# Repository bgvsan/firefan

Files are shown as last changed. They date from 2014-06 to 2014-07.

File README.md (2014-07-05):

Fire Fan
=======

A minimal board for your Fire, manage temperature and 220 Volt Fan.

File Available
=======

-- Eagle Pcb Files (schematics, board, gerber)
-- Microcontroller source code and Hex file
-- Bom list

License
=====
See [License] (LICENSE) file.

Support
======
For any problem or support request mail to me[@]diegosantinelli.it

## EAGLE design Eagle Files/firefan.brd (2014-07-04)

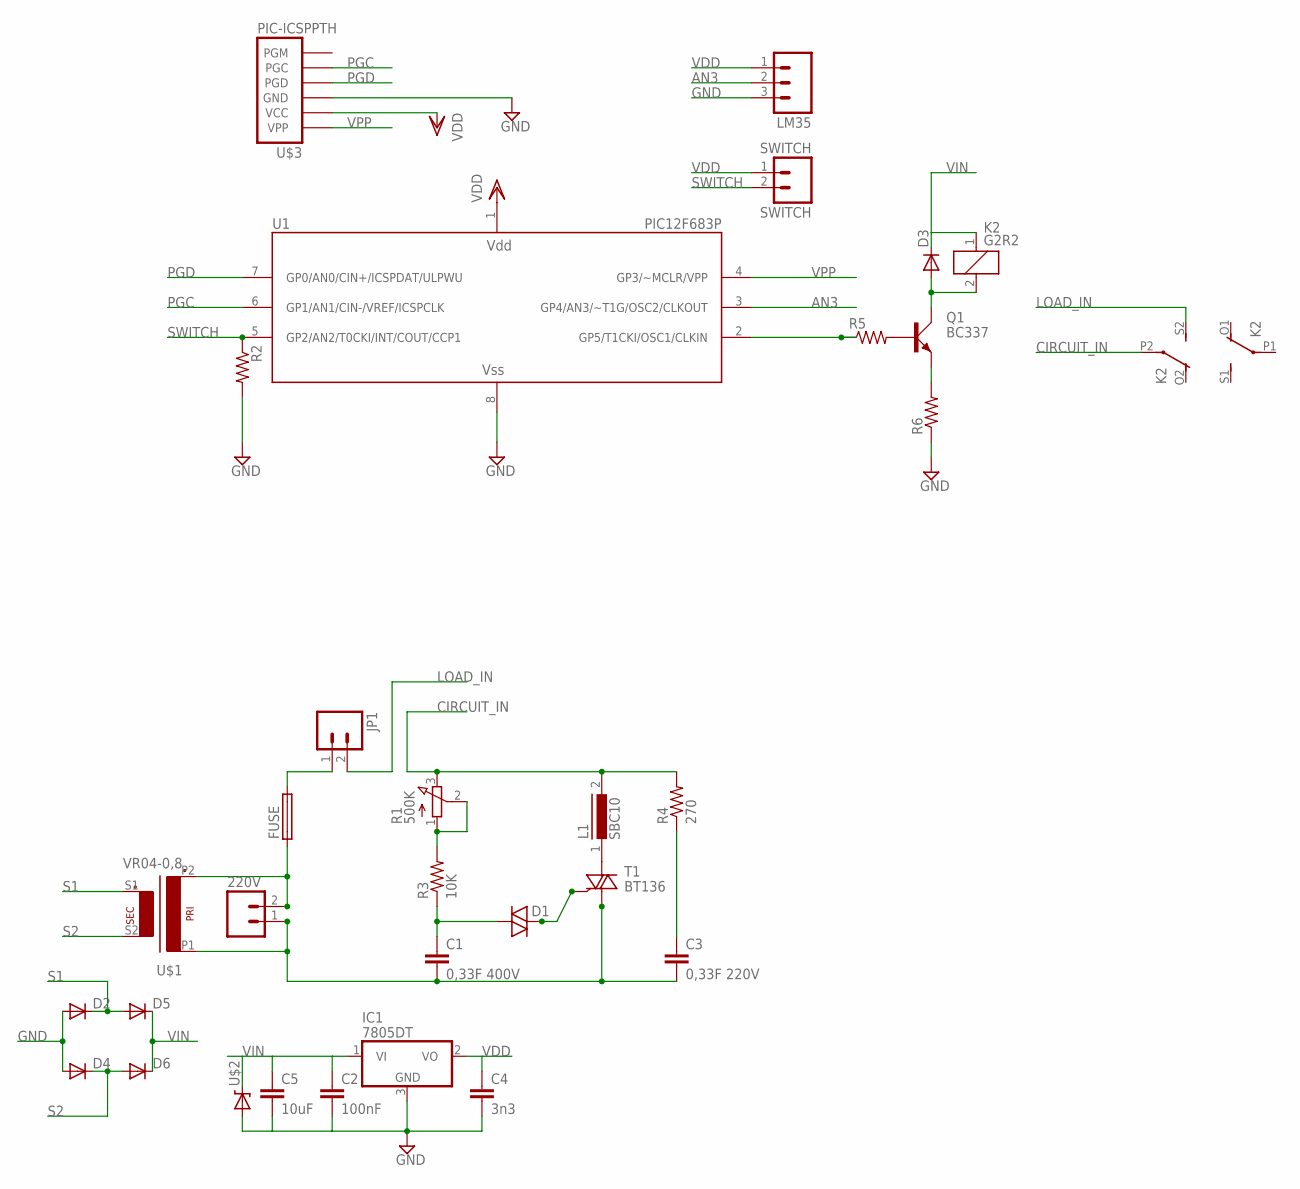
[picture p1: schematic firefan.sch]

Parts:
220V: M023.5MM-NO_SILK; SCREWTERMINAL-3.5MM-2-NS
C1: 0,33F 400V; CAP-PTH-5MM
C2: 100nF; CAP-PTH-5MM
C3: 0,33F 220V; CAP-PTH-5MM
C4: 3n3; CAP-PTH-5MM
C5: 10uF; CAP-PTH-5MM
D1: DIAC-DO35-10; DO35-10
D2, D3, D4, D5, D6: 1N4004; DO41-10
FUSE: SH22,5A
IC1: 7805DT; TO252
JP1: M023.5MM-NO_SILK; SCREWTERMINAL-3.5MM-2-NS
K2: G2R2
L1: SBC10
LM35: M03LONGPADS; 1X03_LONGPADS
Q1: BC337; SOT54A
R1: 500K; 3RP/1610N
R2, R5, R6: RESISTORPTH-1/4W; AXIAL-0.4
R3: 10K; AXIAL-0.5
R4: 270; AXIAL-0.5
SWITCH: SWITCH; SCREWTERMINAL-3.5MM-2-NS
T1: BT136; TO220AB
U1: PIC12F683P; DIP-8
U$1: VR04-0,8
U$2: DIODE-ZENERPTH; DIODE-ZENER
U$3: PIC-ICSPPTH; MOLEX-1X6

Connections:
AN3: LM35.2, U1.3 (GP4/AN3/~T1G/OSC2/CLKOUT)
CIRCUIT_IN: K2.P2, L1.2, R1.3 (E), R4.P$2 (2)
GND: C2.2, C4.2, C5.2, D2.A, D4.A, IC1.3 (GND), LM35.3, R2.P$2 (2), R6.P$1 (1), U1.8 (VSS), U$2.P$2 (A), U$3.3 (GND)
LOAD_IN: JP1.2, K2.S2 (S)
unnamed: FUSE.2, JP1.1
unnamed: D1.C (2), T1.3 (G)
unnamed: R1.1 (A), R1.2 (S), R3.P$2 (2)
unnamed: L1.1, T1.2 (A2)
unnamed: C1.1, D1.A (1), R3.P$1 (1)
unnamed: C3.1, R4.P$1 (1)
unnamed: 220V.1, C1.2, C3.2, T1.1 (A1), U$1.P1
unnamed: 220V.2, FUSE.1, U$1.P2
unnamed: Q1.B, R5.P$2 (2)
unnamed: Q1.E, R6.P$2 (2)
unnamed: D3.A, K2.2, Q1.C
PGC: U1.6 (GP1/AN1/CIN-/VREF/ICSPCLK), U$3.5 (PGC)
PGD: U1.7 (GP0/AN0/CIN+/ICSPDAT/ULPWU), U$3.4 (PGD)
RELAIS: R5.P$1 (1), U1.2 (GP5/T1CKI/OSC1/CLKIN)
S1: D2.C, D5.A, U$1.S1 (S3)
S2: D4.C, D6.A, U$1.S2 (S4)
SWITCH: R2.P$1 (1), SWITCH.2, U1.5 (GP2/AN2/T0CKI/INT/COUT/CCP1)
VDD: C4.1, IC1.2 (VO), LM35.1, SWITCH.1, U1.1 (VDD), U$3.2 (VCC)
VIN: C2.1, C5.1, D3.C, D5.C, D6.C, IC1.1 (VI), K2.1, U$2.P$1 (C)
VPP: U1.4 (GP3/~MCLR/VPP), U$3.1 (VPP)

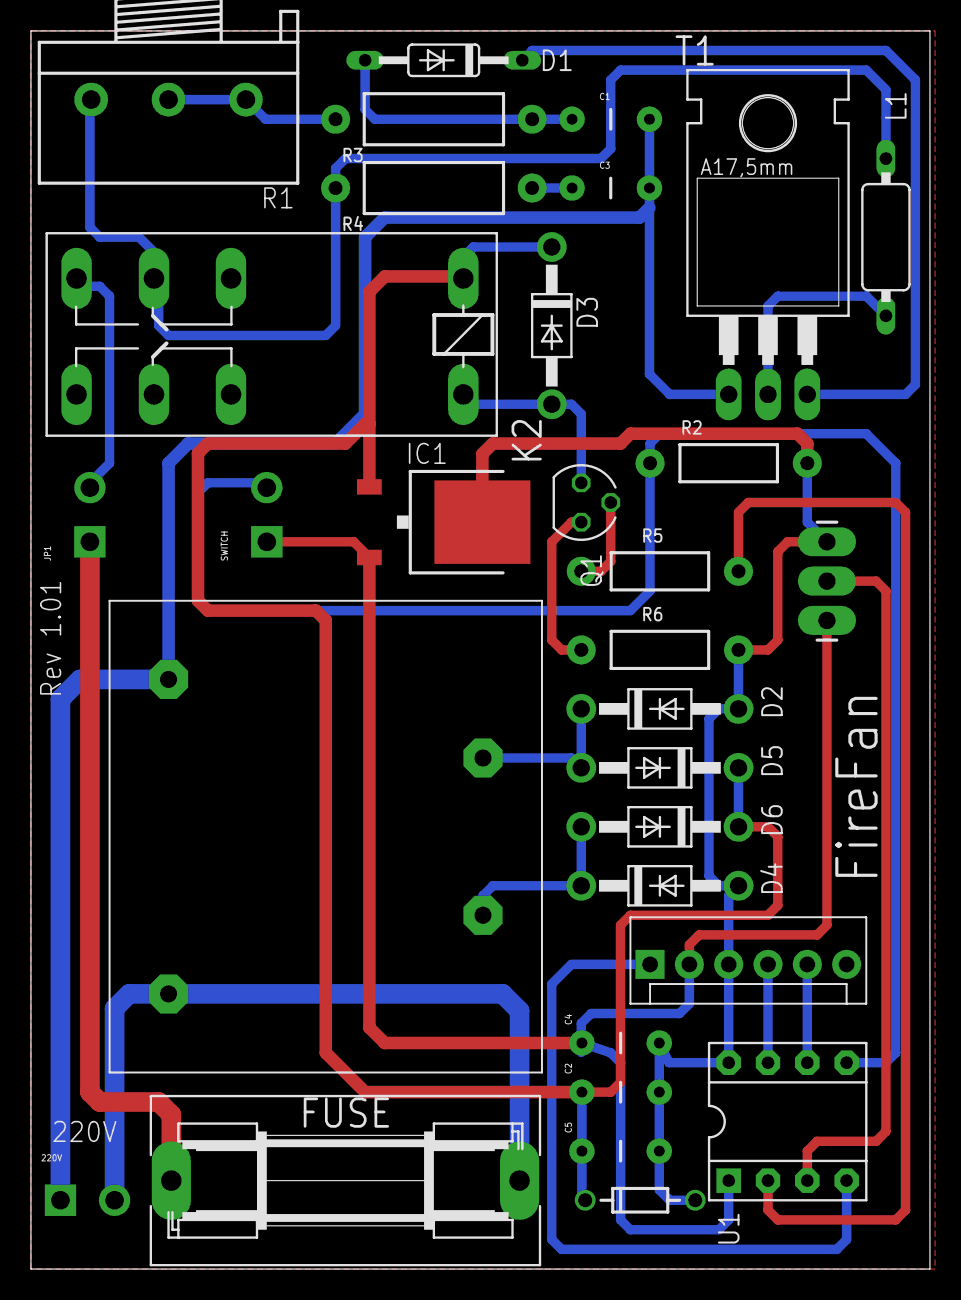
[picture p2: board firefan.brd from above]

Board: 4 copper layers, 58.1 x 80.0 mm, 31 parts (0 on the bottom side), 24 nets.

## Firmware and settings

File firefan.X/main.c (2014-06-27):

/* 
 * File:   main.c
 * Author: Diego Santinelli
 *
 * Created on 15 aprile 2014, 19.15
 */
#include <xc.h>
#include "LM35.h"

#define _XTAL_FREQ 8000000



// CONFIG
#pragma config FOSC = INTOSCIO  // Oscillator Selection bits (INTOSCIO oscillator: I/O function on RA4/OSC2/CLKOUT pin, I/O function on RA5/OSC1/CLKIN)
#pragma config WDTE = OFF       // Watchdog Timer Enable bit (WDT disabled)
#pragma config PWRTE = OFF      // Power-up Timer Enable bit (PWRT disabled)
#pragma config MCLRE = OFF       // MCLR Pin Function Select bit (MCLR pin function is MCLR)
#pragma config CP = OFF         // Code Protection bit (Program memory code protection is disabled)
#pragma config CPD = OFF        // Data Code Protection bit (Data memory code protection is disabled)
#pragma config BOREN = OFF      // Brown Out Detect (BOR disabled)
#pragma config IESO = OFF       // Internal External Switchover bit (Internal External Switchover mode is disabled)
#pragma config FCMEN = ON       // Fail-Safe Clock Monitor Enabled bit (Fail-Safe Clock Monitor is enabled)



void init()
{

    //ALL INPUT //GP5 OUTPUT
    TRISIO = 0b011111;


    //ADC define
    ADCON0 = 0b00001101;
            ///0------- LEFT Giustified
            ///----11-- AN3 active
            ///------0- GODONE
            ///-------1 ADON

    CMCON0bits.CM = 0b111;

}


void main(void) {

     
    init();

    while(1)
    {

        if (switchOn())
        {

            GPIObits.GP5 = 1;
            //GPIO = 0b010000;

        }
        else
            GPIObits.GP5 = 0;
            

        //__delay_ms(5000);
    }
}

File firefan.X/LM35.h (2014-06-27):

/* 
 * File:   LM35.h
 * Author: diego
 *
 * Created on 25 aprile 2014, 9.55
 */

#ifndef LM35_H
#define	LM35_H


#ifdef	__cplusplus
extern "C" {
#endif




#ifdef	__cplusplus
}
#endif

#endif	/* LM35_H */

#define maxTemperature 60
#define minTemperature 50

//calculate the temperature from the AN3 LM35 connected
float getTemperature(void);
int switchOn(void);

float getTemperature()

{
    float temperature;
    ADCON0bits.GO = 1;
    while(ADCON0bits.GO_nDONE)
    {
        ;
    }

    //unsigned int ADvalue = ADRESH;
    unsigned int ADvalue=ADRESL + (ADRESH << 8);
    int rawvoltage= (ADvalue>>6);
    float millivolts= (rawvoltage/1024.0) * 5000;
    float temperature= millivolts/10;

    return temperature;

}

int switchOn(void)
{
    float temperature ;
    temperature = getTemperature();

    if(GPIObits.GP5 == 0)
    {
        if (temperature > maxTemperature)
            return 1;
        else
            return 0;
    }
    else
    {
        if(temperature < minTemperature)
            return 0;
        else
            return 1;
    }

}

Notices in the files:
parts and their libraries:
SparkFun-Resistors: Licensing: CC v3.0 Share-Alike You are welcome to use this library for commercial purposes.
